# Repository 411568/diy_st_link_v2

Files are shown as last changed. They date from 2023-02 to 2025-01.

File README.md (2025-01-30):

<p align="center">diy_st_link_v2</p>

<h2>🧐 Features</h2>

ST-LINK is a programmer used with STM32 microcontrollers. It is sold by STMicroelectronics and by many other manufacturers and is included in a number of Nucleo/Discovery/etc. development boards.
Because of that, the schematics for it are available on the internet and you can build one yourself... and that is what I did.

My schematic was inspired by two diy projects, available under the following links: [STM32World](https://stm32world.com/wiki/DIY_STM32_Programmer_(ST-Link/V2-1)), [EmbdedBlog](https://embedblog.eu/?p=780). 
The design was then compared with one of STMs own designs from a Nucleo board.
You may think that the schematics could be easily reverse engineered, but you can't get the firmware for it, as it is proprietary STM softwa, right? Well, it seems someone has already done the job for us: [bootloader](https://github.com/Krakenw/Stlink-Bootloaders).

The schematic and PCB were both designed using KiCAD 6.0

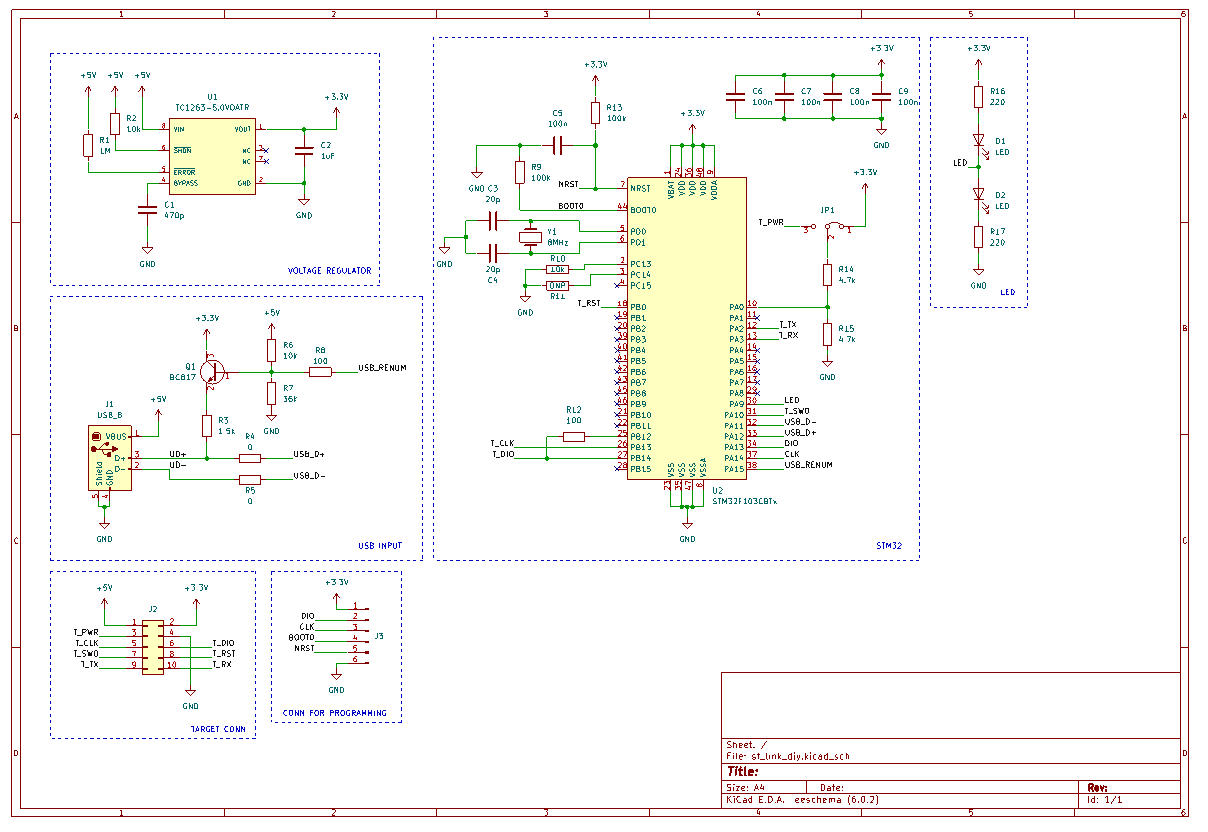
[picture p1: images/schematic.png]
Schematic kicad


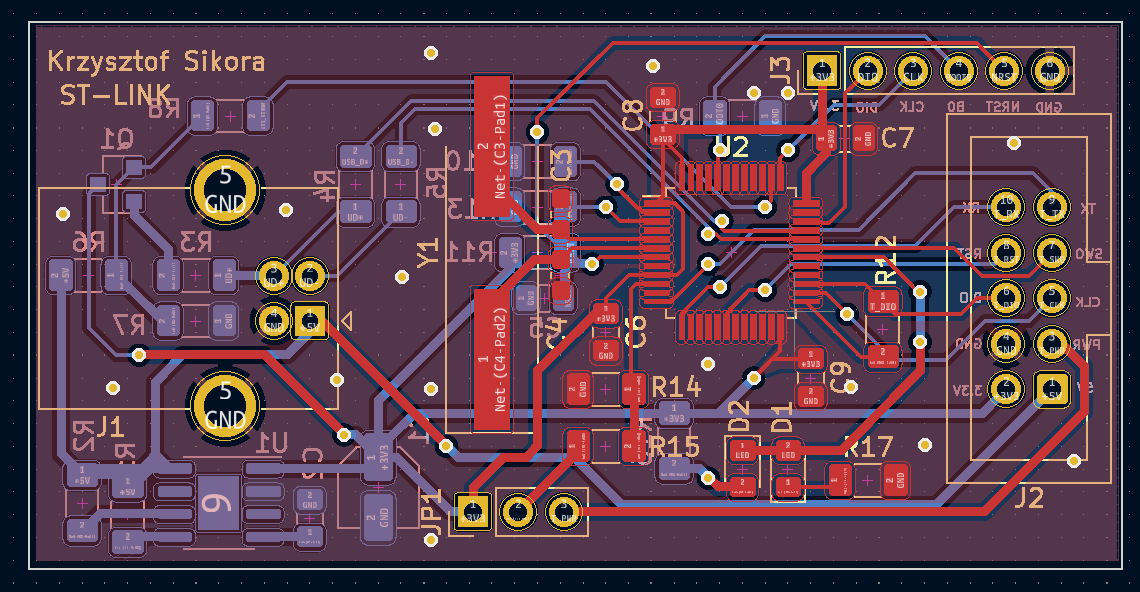
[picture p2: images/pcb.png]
PCB kicad


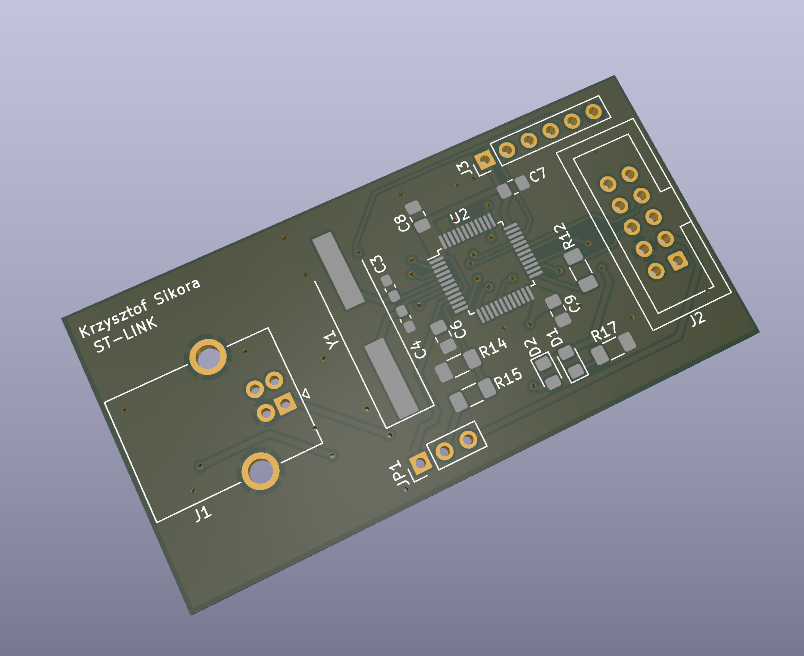
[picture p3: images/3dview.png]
3d view


<h2>💻 Parts list</h2>

* STM32F103C8T6 microcontroller (you can use the CBT6 for more memory)
* TC1263 3.3V linear regulator
* IDC connector
* pin header for programming
* USB B connector
* 2x 0805 SMD LED
* 2x 220Ohm resistor
* 2x 100Ohm resistor
* 1MOhm resistor
* 3x 10kOhm resistor
* 2x 100kOhm resistor
* 2x 4.7kOhm resistor
* 1.5kOhm resistor
* 36kOhm resistor
* 470pF ceramic capacitor
* 1uF electrolytic capacitor
* 4x 100nF ceramic capacitor
* 2x 20pF ceramic capacitor

<h2>📝 Assembled project</h2>

st link photo

<h2>🛡️ License:</h2>

This project is licensed under the MIT License.

<h2> 🙋‍♂️Authors </h2>

- Krzysztof Sikora

<h2>💖Like my work?</h2>

If you have any questions about the project feel free to contact us via email: krzysieksikora717@gmail.com

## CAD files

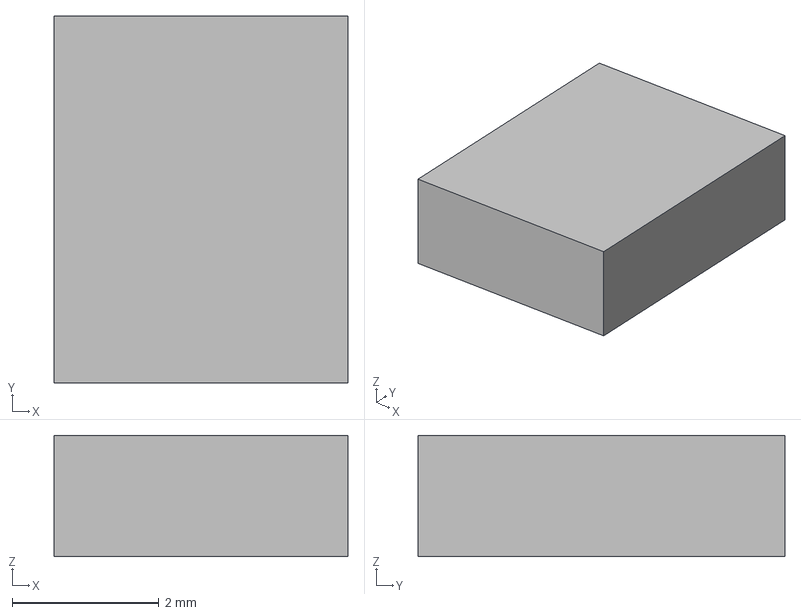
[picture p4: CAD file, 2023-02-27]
KICAD_FILES/st_link_diy/eec.models/Microchip_-_TC1263-5.0VOATR.step
4.00 x 5.00 x 1.65 mm

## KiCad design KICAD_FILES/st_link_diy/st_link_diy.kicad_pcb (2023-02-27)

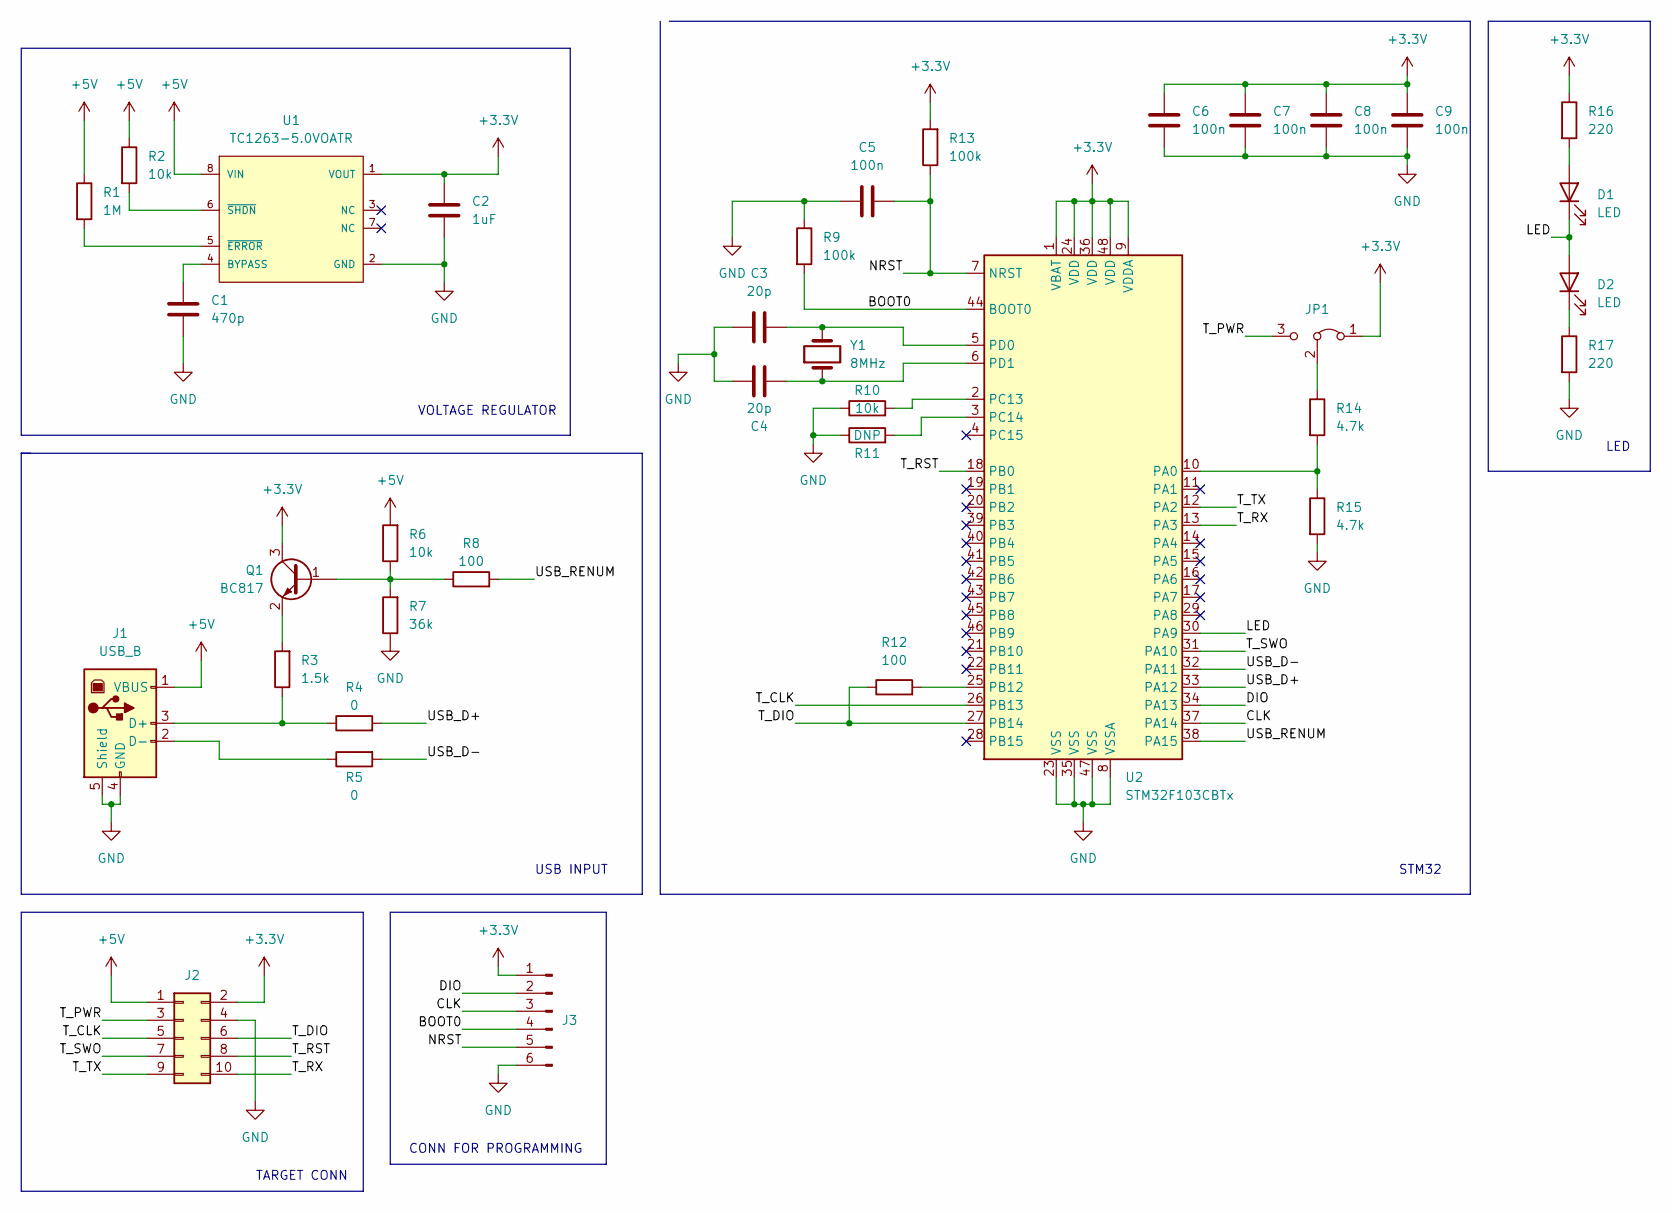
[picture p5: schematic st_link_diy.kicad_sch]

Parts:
C1: 470p; C_0805_2012Metric_Pad1.18x1.45mm_HandSolder
C2: 1uF; C_Elec_4x5.4
C3, C4: 20p; C_0603_1608Metric_Pad1.08x0.95mm_HandSolder
C5, C6, C7, C8, C9: 100n; C_0805_2012Metric_Pad1.18x1.45mm_HandSolder
D1, D2: LED; LED_0805_2012Metric_Pad1.15x1.40mm_HandSolder
J1: USB_B; USB_B_OST_USB-B1HSxx_Horizontal
J2: Conn_02x05_Odd_Even; IDC-Header_2x05_P2.54mm_Vertical
J3: Conn_01x06_Male; PinHeader_1x06_P2.54mm_Vertical
JP1: Jumper_3_Bridged12; PinHeader_1x03_P2.54mm_Vertical
Q1: BC817; SOT-23
R1: 1M; R_1206_3216Metric_Pad1.30x1.75mm_HandSolder
R2, R6, R10: 10k; R_1206_3216Metric_Pad1.30x1.75mm_HandSolder
R3: 1.5k; R_1206_3216Metric_Pad1.30x1.75mm_HandSolder
R4, R5: 0; R_1206_3216Metric_Pad1.30x1.75mm_HandSolder
R7: 36k; R_1206_3216Metric_Pad1.30x1.75mm_HandSolder
R8, R12: 100; R_1206_3216Metric_Pad1.30x1.75mm_HandSolder
R9, R13: 100k; R_1206_3216Metric_Pad1.30x1.75mm_HandSolder
R11: DNP; R_1206_3216Metric_Pad1.30x1.75mm_HandSolder
R14, R15: 4.7k; R_1206_3216Metric_Pad1.30x1.75mm_HandSolder
R16, R17: 220; R_1206_3216Metric_Pad1.30x1.75mm_HandSolder
U1: TC1263-5.0VOATR; SOIC-8-1EP_3.9x4.9mm_P1.27mm_EP2.29x3mm
U2: STM32F103CBTx; LQFP-48_7x7mm_P0.5mm
Y1: 8MHz; Crystal_SMD_HC49-SD_HandSoldering

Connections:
+3V3: C2.1, C6.1, C7.1, C8.1, C9.1, J2.2, J3.1, JP1.1 (A), Q1.3 (C), R13.2, R16.1, U1.1 (VOUT), U2.1 (VBAT), U2.9 (VDDA), U2.24 (VDD), U2.36 (VDD), U2.48 (VDD)
+5V: J1.1 (VBUS), J2.1, R1.1, R2.1, R6.2, U1.8 (VIN)
/BOOT0: J3.4, R9.2, U2.44 (BOOT0)
/CLK: J3.3, U2.37 (PA14)
/DIO: J3.2, U2.34 (PA13)
/LED: D1.1 (K), D2.2 (A), U2.30 (PA9)
/NRST: C5.2, J3.5, R13.1, U2.7 (NRST)
/T_CLK: J2.5, U2.26 (PB13)
/T_DIO: J2.6, R12.1, U2.27 (PB14)
/T_PWR: J2.3, JP1.3 (B)
/T_RST: J2.8, U2.18 (PB0)
/T_RX: J2.10, U2.13 (PA3)
/T_SWO: J2.7, U2.31 (PA10)
/T_TX: J2.9, U2.12 (PA2)
/USB_D+: R4.2, U2.33 (PA12)
/USB_D-: R5.2, U2.32 (PA11)
/USB_RENUM: R8.2, U2.38 (PA15)
GND: C1.2, C2.2, C3.2, C4.1, C5.1, C6.2, C7.2, C8.2, C9.2, J1.4 (GND), J1.5 (Shield), J2.4, J3.6, R7.1, R9.1, R10.1, R11.1, R15.2, R17.2, U1.2 (GND), U2.8 (VSSA), U2.23 (VSS), U2.35 (VSS), U2.47 (VSS)
unnamed: C1.1, U1.4 (BYPASS)
unnamed: C3.1, U2.5 (PD0), Y1.2
unnamed: C4.2, U2.6 (PD1), Y1.1
unnamed: D1.2 (A), R16.2
unnamed: D2.1 (K), R17.1
unnamed: J1.2 (D-), R5.1
unnamed: J1.3 (D+), R3.1, R4.1
unnamed: JP1.2 (C), R14.1
unnamed: Q1.1 (B), R6.1, R7.2, R8.1
unnamed: Q1.2 (E), R3.2
unnamed: R1.2, U1.5 (~ERROR)
unnamed: R2.2, U1.6 (~SHDN)
unnamed: R10.2, U2.2 (PC13)
unnamed: R11.2, U2.3 (PC14)
unnamed: R12.2, U2.25 (PB12)
unnamed: R14.2, R15.1, U2.10 (PA0)

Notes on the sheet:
STM32
TARGET CONN
VOLTAGE REGULATOR
USB INPUT
LED
CONN FOR PROGRAMMING

Board: 2 copper layers, 36 parts (0 on the bottom side), 34 nets, no tracks yet.

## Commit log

2023-02-27 added schematic v0.1
    [Microchip_-_TC1263-5.0VOATR.step, st_link_diy.kicad_sch]
2023-02-27 finished schematic
    [st_link_diy.kicad_pcb, st_link_diy.kicad_sch]
2023-02-27 added pcb
    [st_link_diy.kicad_pcb]
2023-02-28 added pcb panel and gerbers
    [st_link_diy - Copy.kicad_pcb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]
2023-03-01 added readme
    [st_link_diy_panel.kicad_pcb]
